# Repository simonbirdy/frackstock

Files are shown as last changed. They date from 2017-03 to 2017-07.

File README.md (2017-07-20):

# frackstock
LED walking stick  for the Frackwoche 2017 www.frackwoche.ch

The LED walking stick contains 100 WS2812B RGB-LEDs which can be adressed seperately. The walking stick can be controlled with a accelometer or remotely via a 968 MHz RF-Link. This allows a master to control all walking sticks in range 

Videos showing the walking stick in Action:

(https://www.youtube.com/watch?v=WOQ_-gf9qqU)

(https://www.youtube.com/watch?v=yyVRBFyqIFY)

General Setup (Remote Control):

Android Device (WLAN) -> Sender (ESP2866 & RFM117) -> walking stick (RFM217 & STM32f0)

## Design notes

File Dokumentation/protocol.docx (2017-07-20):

# Sender Protocol

The Protocol consists out of 8 bytes:

START | SESSION | TARGET | COMMAND | PAR1 | PAR2 | PAR3 | CHECKSUM

# START

Hex-Value = 0xAA

1 | 0 | 1 | 0 | 1 | 0 | 1 | 0

Signals the start of a transmission.

# SESSION

B7 | B6 | B5 | B4 | B3 | B2 | B1 | B0

B7..B0 Number of session

The session number is used to differ between new commands and repeated commands. Each command is sent twice with the same session number to produce redundancy.

# TARGET

B7 | B6 | B5 | B4 | B3 | B2 | B1 | B0
MODE

B7..B6 00=MODE_ADRESS

01=MODE_EXCLUDE

10=MODE_MODULO

11=RESERVED

MODE_ADRESS:

B5..B0 Adress of device (Broadcast=0x3F) to receive Command

MODE_EXCLUDE:

B5..B0 Adress of device (Broadcast=0x3F) to ignore Command

MODE_MODULO

B2..B1 Modulo value (e.g 3-> every third device reacts on command)

B5..B3 Offset value (e.g. 1 -> device 1,4,7… 2-> device 2,5,8…)

## COMMAND

B7 | B6 | B5 | B4 | B3 | B2 | B1 | B0
Background

B7 0=Trigger Foreground Animation

1=Background Animation

B6..B0 Animation identifier

## PAR1..3

Parameters for the Animation

## CHECKSUM

B7 | B6 | B5 | B4 | B3 | B2 | B1 | B0

Checksum = SESSION+TARGET+COMMAND+PAR1+PAR2+PAR3

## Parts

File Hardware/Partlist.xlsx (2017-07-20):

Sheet: Tabelle1
Part | Value | Device | Package | Library | Supplier | Order number | Price
U2 |  | MCP1700-T-3302 |  |  | Farnell | 1296592 | 0.343 | 50
U4 |  | TPS61235 |  |  | Mouser | 595-TPS61235PRWLR | 1.8 | 5
U3 |  | STM32F031 |  |  | Farnell | 2503233 | 1.41 | 50
U1 |  | MMA7660FCR1 |  |  | Farnell | 2080493 | 1.24 | 40
U5 |  | RFM217 |  |  | vogelsi1 |  |  | 39
C7,C8,C9,C14 | 22uF / 10V | Kondensator | 805 |  | Mouser | 81-GRM188R61A226ME5D (http://www.mouser.ch/ProductDetail/Murata-Electronics/GRM188R61A226ME15D/) |  | 200
C13 | 10 uF / 10V | Kondensator | 805 |  | Mouser |  |  | 50
L1 | 1 uH | SRN80401A |  |  | Mouser | 652-SRN8040-1R0Y | 0.4 | 5
C1,C3,C5 | 100nF |  | 603 |  | Mouser | 81-GRM39X104K25 |  | 150
R1 | 1k |  | 603 |  | Mouser | 667-ERJ-1GEJ102C |  | 100
R2,R3 | 4.7k |  | 603 |  | Mouser | 667-ERJ-1GEJ472C |  | 100
R9,R10 | 10k |  | 603 |  | Mouser | 603-RC0201FR-0710KL |  | 100
R11 | 22k |  | 603 |  | Mouser | 603-RC0201FR-0722KL | 0.01 | 100
K1 |  |  |  |  | Farnell | 1565585 |  | -
 |  | Batteriehalter |  |  |  |  | 1.3

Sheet: Tabelle2
Was | Wer | Wieviel | Bezahlt
LED Strip 4x | Ueli | 76
Livio Stöcke | Simon | 535
Livio Prototyp | Livio | 20
Led Strip 2x | Adrian | 38
Led Strip 6x | Simon | 104
PCB | Adrian | 142
LaserCutting | Simon | 220
Bauteile | Ueli | 231
Holz | Sven | 54
Bauteile | Simon | 116.75
Schrauben & Co | Ueli | 85.2
Gehstockpuffer | Simon | 20
 |  | 1641.95 | 49.75606061
Kosten pro Stock
LED |  | 6.61
PCB |  | 14.84
Stock |  | 16.82
Knauf |  | 10.88
Total |  | 49.15

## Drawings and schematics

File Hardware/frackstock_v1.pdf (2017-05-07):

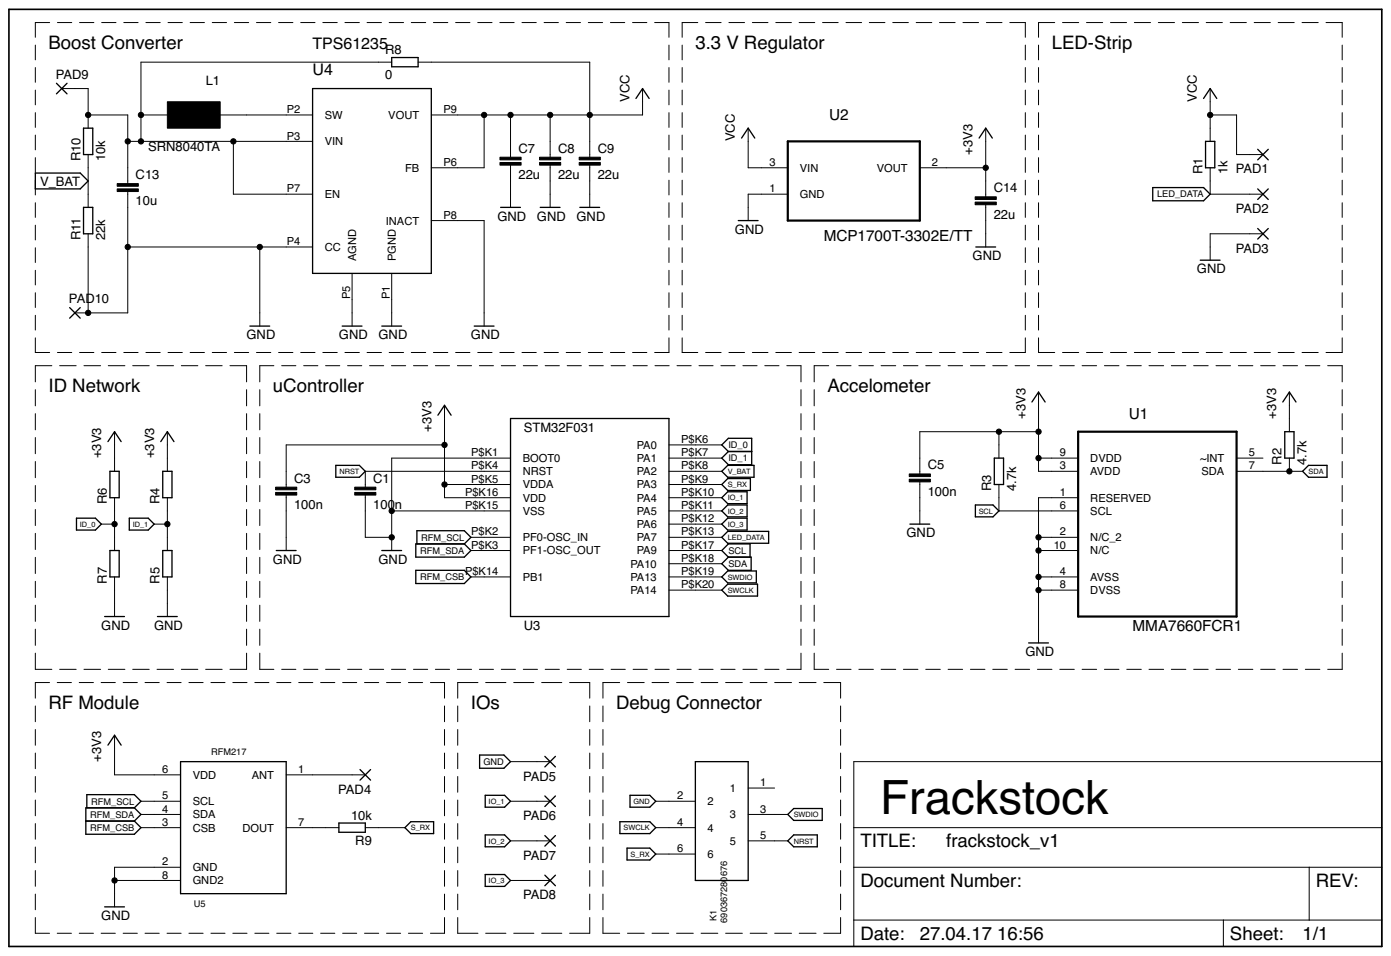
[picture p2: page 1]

Document Number: | REV:

Date: 27.04.17 16:56 | Sheet: 1/1

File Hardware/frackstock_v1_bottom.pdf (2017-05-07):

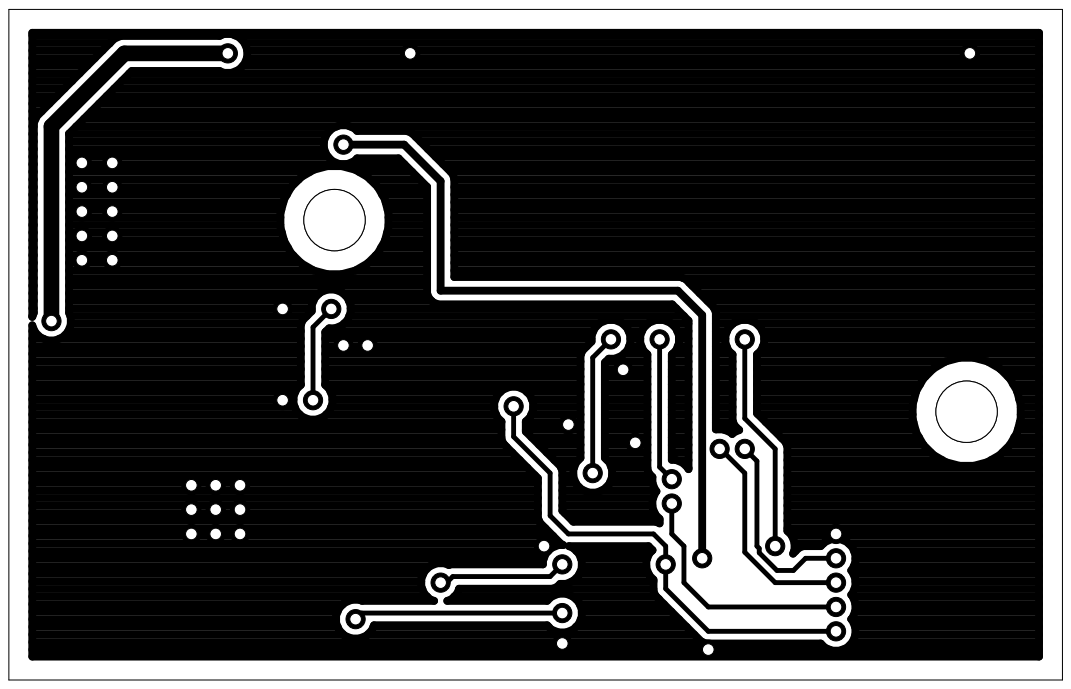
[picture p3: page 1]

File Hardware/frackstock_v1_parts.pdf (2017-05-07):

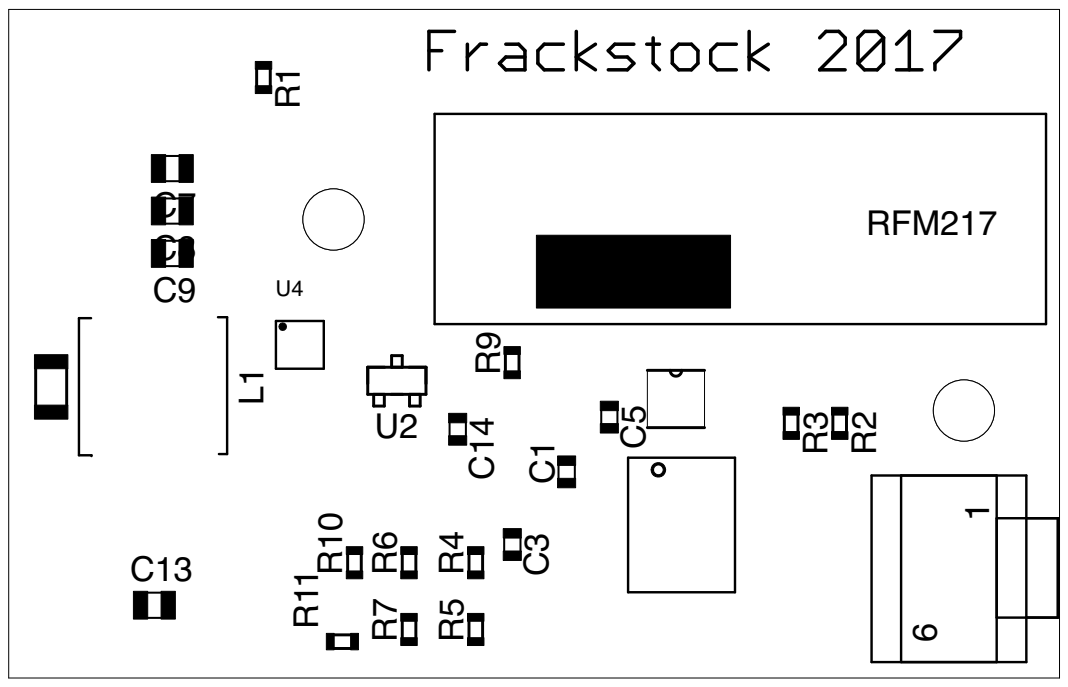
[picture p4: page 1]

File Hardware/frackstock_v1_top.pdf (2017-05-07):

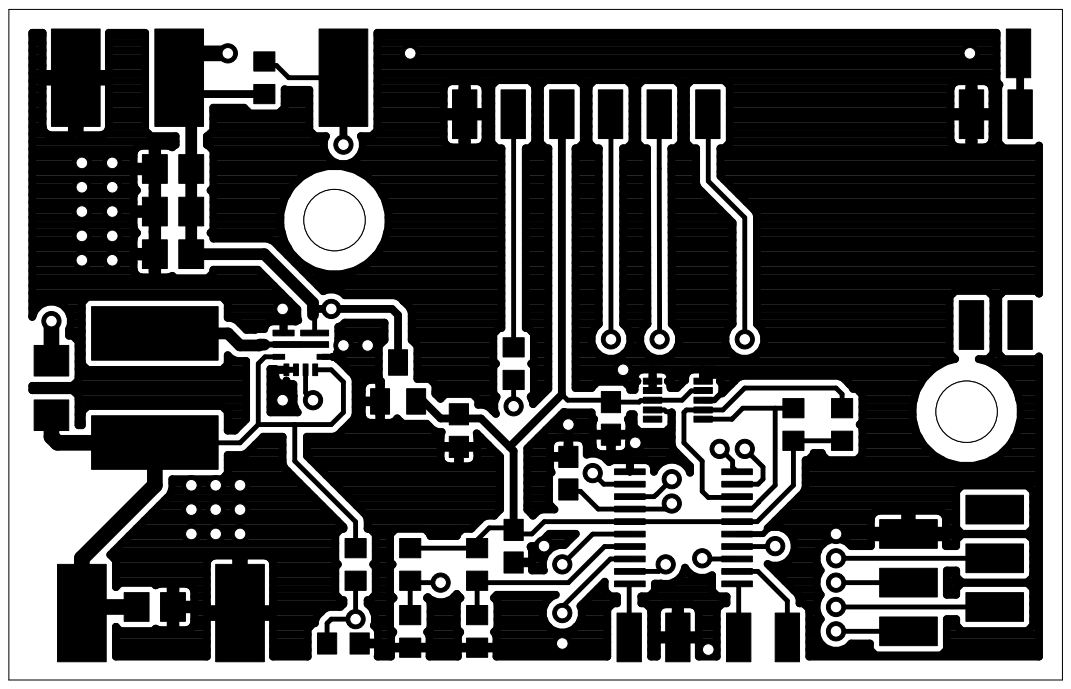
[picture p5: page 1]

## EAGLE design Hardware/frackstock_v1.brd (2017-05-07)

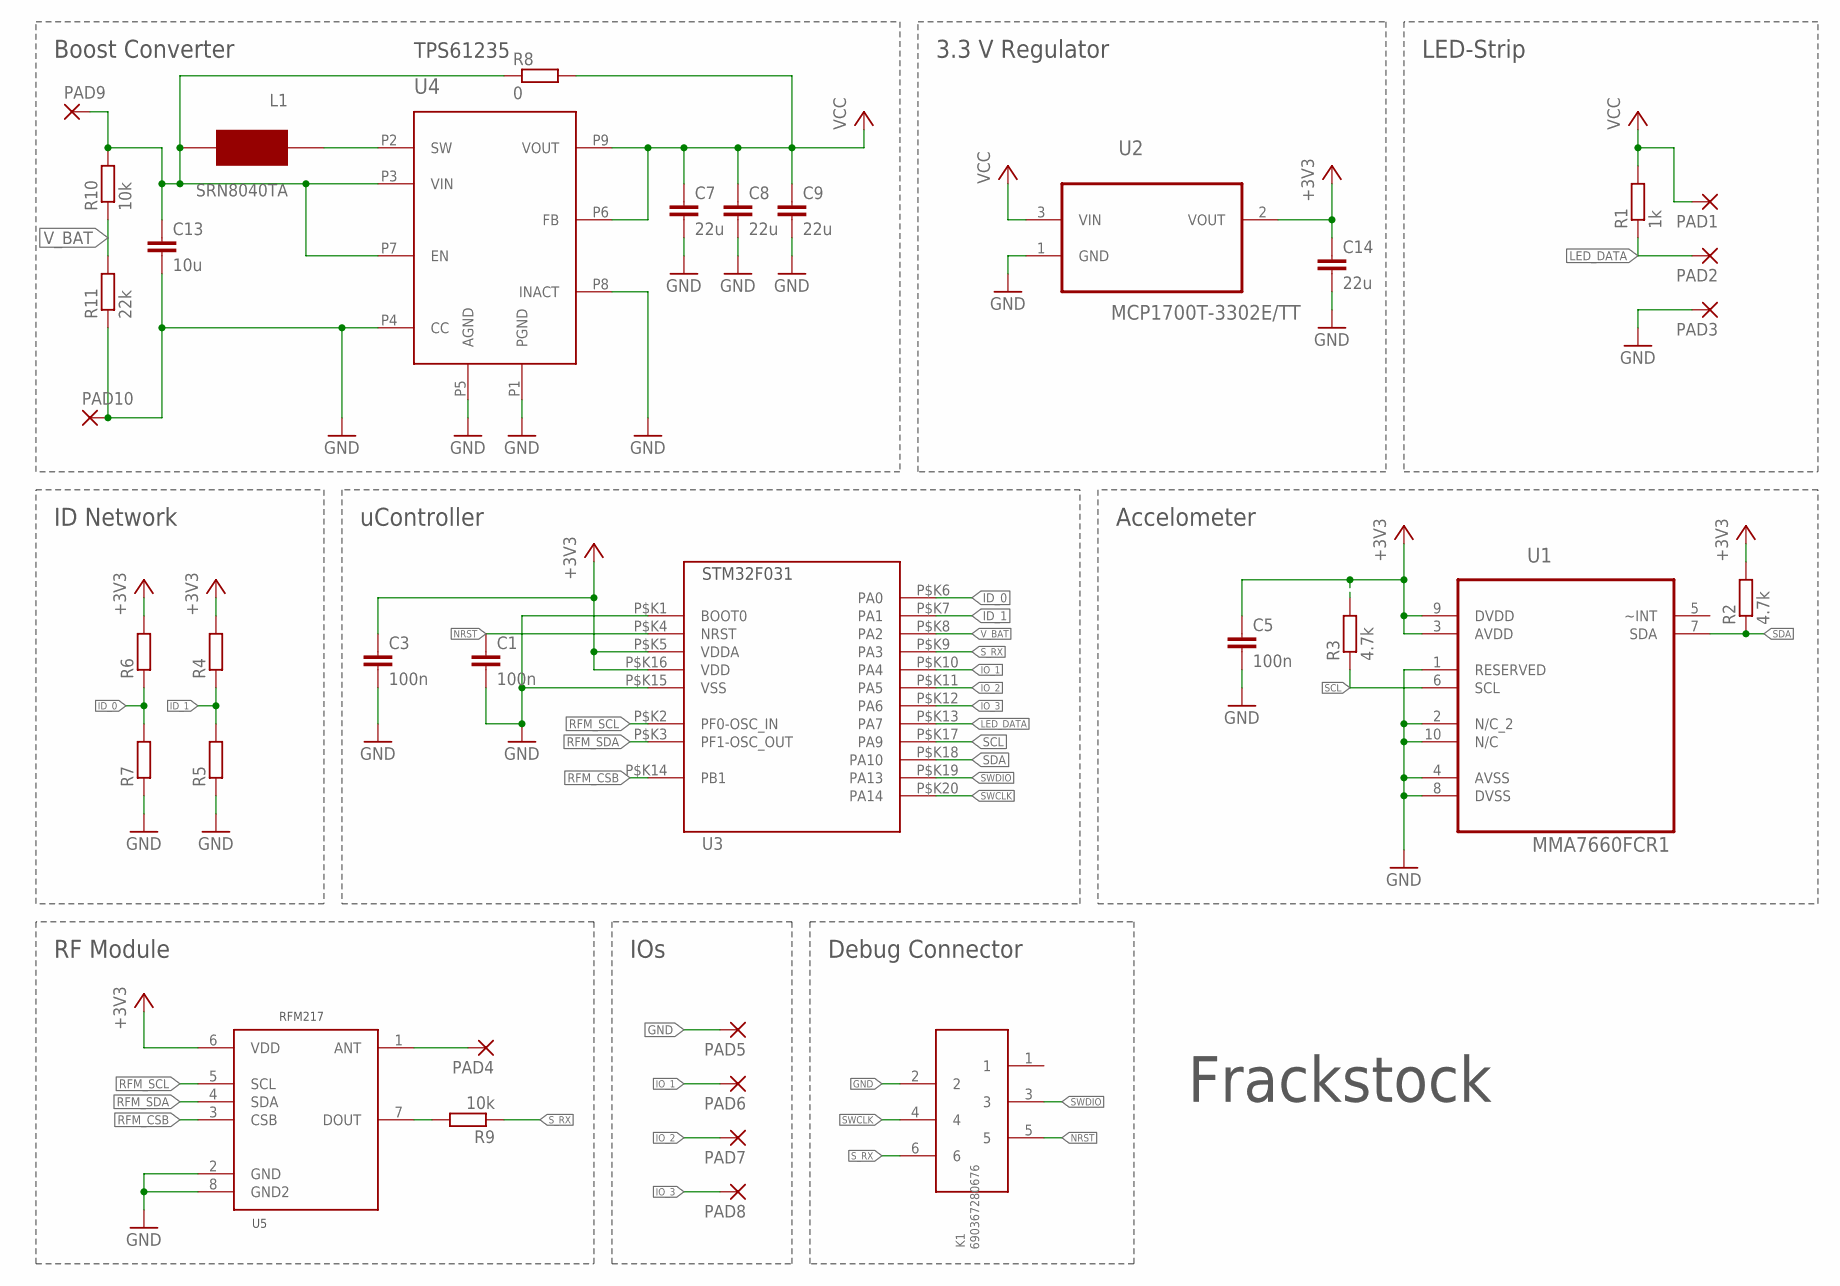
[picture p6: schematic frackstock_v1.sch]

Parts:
C1, C3, C5: 100n; C0603
C7, C8, C9: 22u; C0805
C13: 10u; C0805
C14: 22u; C0603
K1: 690367280676
L1: SRN8040TA; SRN8040TA_PACK
PAD1, PAD2, PAD3, PAD9, PAD10: SMD5; SMD2,54-5,08
PAD4, PAD5, PAD6, PAD7, PAD8: SMD2; SMD1,27-2,54
R1: 1k; R0603
R2, R3: 4.7k; R0603
R4, R5, R6, R7: R-EU_R0603; R0603
R8: 0; R1206
R9, R10: 10k; R0603
R11: 22k; R0603
U1: MMA7660FCR1; DFN300X300X100-10N
U2: MCP1700T-3302E/TT; SOT95P237X112-3N
U3: STM32F031; TSSOP20
U4: TPS61235; VQFN
U5: RFM217; RFM217_PACK

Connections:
+3V3: C3.1, C5.1, C14.1, R2.2, R3.2, R4.2, R6.2, U1.3 (AVDD), U1.9 (DVDD), U2.2 (VOUT), U3.P$K5 (VDDA), U3.P$K16 (VDD), U5.6 (VDD)
GND: C1.2, C3.2, C5.2, C7.2, C8.2, C9.2, C13.2, C14.2, K1.2, PAD3.1, PAD5.1, PAD10.1, R5.1, R7.1, R11.1, U1.1 (RESERVED), U1.2 (N/C_2), U1.4 (AVSS), U1.8 (DVSS), U1.10 (N/C), U2.1 (GND), U3.P$K1 (BOOT0), U3.P$K15 (VSS), U4.P1 (PGND), U4.P4 (CC), U4.P5 (AGND), U4.P8 (INACT), U5.2 (GND), U5.8 (GND2)
ID_0: R6.1, R7.2, U3.P$K6 (PA0)
ID_1: R4.1, R5.2, U3.P$K7 (PA1)
IO_1: PAD6.1, U3.P$K10 (PA4)
IO_2: PAD7.1, U3.P$K11 (PA5)
IO_3: PAD8.1, U3.P$K12 (PA6)
LED_DATA: PAD2.1, R1.1, U3.P$K13 (PA7)
unnamed: R9.2, U5.7 (DOUT)
unnamed: PAD4.1, U5.1 (ANT)
unnamed: L1.2, U4.P2 (SW)
unnamed: C13.1, L1.1, PAD9.1, R8.1, R10.2, U4.P3 (VIN), U4.P7 (EN)
NRST: C1.1, K1.5, U3.P$K4 (NRST)
RFM_CSB: U3.P$K14 (PB1), U5.3 (CSB)
RFM_SCL: U3.P$K2 (PF0-OSC_IN), U5.5 (SCL)
RFM_SDA: U3.P$K3 (PF1-OSC_OUT), U5.4 (SDA)
SCL: R3.1, U1.6 (SCL), U3.P$K17 (PA9)
SDA: R2.1, U1.7 (SDA), U3.P$K18 (PA10)
SWCLK: K1.4, U3.P$K20 (PA14)
SWDIO: K1.3, U3.P$K19 (PA13)
S_RX: K1.6, R9.1, U3.P$K9 (PA3)
VCC: C7.1, C8.1, C9.1, PAD1.1, R1.2, R8.2, U2.3 (VIN), U4.P6 (FB), U4.P9 (VOUT)
V_BAT: R10.1, R11.2, U3.P$K8 (PA2)

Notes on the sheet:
Frackstock
Boost Converter
3.3 V Regulator
LED-Strip
ID Network
uController
Debug Connector
IOs
RF Module
Accelometer

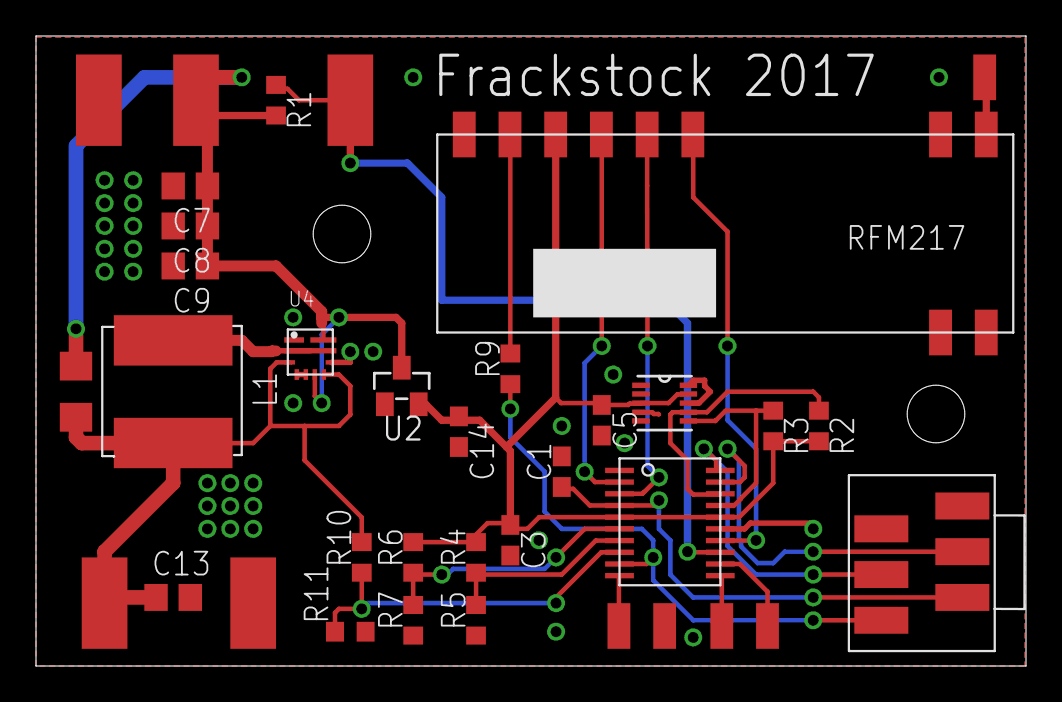
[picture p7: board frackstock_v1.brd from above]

Board: 2 copper layers, 55.0 x 35.0 mm, 36 parts (0 on the bottom side), 23 nets.

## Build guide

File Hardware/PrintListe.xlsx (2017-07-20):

Print | R4 | R5 | R6 | R7 | Bemerkungen | Name |  | 0
1 |  | 0 | 0 |  |  |  | 300 | 33 | 405.9099099
2 | 200 | 33 | 0 |  |  |  | 30 | 12 | 1170.285714
3 | 30 | 12 | 0 |  |  |  | 16 | 12 | 1755.428571
4 | 16 | 12 | 0 |  |  |  | 7.5 | 10 | 2340.571429
5 | 7.5 | 10 | 0 |  |  |  | 12 | 30 | 2925.714286
6 | 12 | 30 | 0 |  |  |  | 2 | 12 | 3510.857143
7 | 2 | 12 | 0 |  |  |  | 0 |  | #DIV/0!
8 | 0 |  | 0
9 |  | 0 | 200 | 33
10 | 200 | 33 | 200 | 33
11 | 30 | 12 | 200 | 33
12 | 16 | 12 | 200 | 33
13 | 7.5 | 10 | 200 | 33
14 | 12 | 30 | 200 | 33
15 | 2 | 12 | 200 | 33
16 | 0 |  | 200 | 33
17 |  | 0 | 30 | 12
18 | 200 | 33 | 30 | 12
19 | 30 | 12 | 30 | 12
20 | 16 | 12 | 30 | 12
21 | 7.5 | 10 | 30 | 12
22 | 12 | 30 | 30 | 12
23 | 2 | 12 | 30 | 12
24 | 0 |  | 30 | 12
25 |  | 0 | 16 | 12
26 | 200 | 33 | 16 | 12
27 | 30 | 12 | 16 | 12
28 | 16 | 12 | 16 | 12
29 | 7.5 | 10 | 16 | 12
30 | 12 | 30 | 16 | 12
31 | 2 | 12 | 16 | 12
32 | 0 |  | 16 | 12
33 |  | 0 | 7.5 | 10
34 | 200 | 33 | 7.5 | 10
35 | 30 | 12 | 7.5 | 10
36 | 16 | 12 | 7.5 | 10
37 | 7.5 | 10 | 7.5 | 10
38 | 12 | 30 | 7.5 | 10
39 | 2 | 12 | 7.5 | 10
40 | 0 |  | 7.5 | 10

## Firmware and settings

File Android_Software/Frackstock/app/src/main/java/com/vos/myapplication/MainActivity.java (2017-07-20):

package com.vos.myapplication;

import android.content.Intent;
import android.graphics.Color;
import android.os.Bundle;
import android.support.design.widget.FloatingActionButton;
import android.support.v7.app.AppCompatActivity;
import android.support.v7.widget.Toolbar;
import android.util.Log;
import android.view.MotionEvent;
import android.view.View;
import android.view.Menu;
import android.view.MenuItem;
import android.view.WindowManager;
import android.widget.Button;
import android.widget.EditText;
import android.widget.SeekBar;


public class MainActivity extends AppCompatActivity {

    Button bTriggers, bStripe, bSparks, bConstColor, bRainbow,bBlink,bRain,bStrobo;
    MainActivity thisActivity;
    SeekBar sbGlobalBrightness;

    static int R_SPARKS = 1;
    static int R_STRIPE = 2;
    static int R_CONST = 3;
    static int R_RAINBOW = 4;
    static int R_BLINK = 5;
    static int R_RAIN = 6;
    static int R_STROBO = 7;

    int Sparkscolor1;
    int SparkModulo;
    int SparkSpeed;


    int StripeColor1,StripeColor2;
    int StripeBrightness,StripeLength,StripeSpeed;

    int ConstColor1,ConstColor2,ConstBrightness;

    int RainbowSpeed;

    int BlinkColor1,BlinkColor2,BlinkColor3,BlinkColor4;

    int RainColor1,RainColor2,RainColor3,RainColor4;
    int RainSpeed,RainLength;

    int StroboColor1;
    int StroboLength,StroboPause;


    @Override
    protected void onCreate(Bundle savedInstanceState) {
        super.onCreate(savedInstanceState);
        setContentView(R.layout.activity_main);
        Toolbar toolbar = (Toolbar) findViewById(R.id.toolbar);
        setSupportActionBar(toolbar);


        bBlink = (Button) findViewById(R.id.bBlink);
        bStripe = (Button)  findViewById(R.id.bStripeLaunch);
        bSparks = (Button) findViewById(R.id.bSparksLaunch);
        bConstColor = (Button)    findViewById(R.id.bConstColor);
        bRainbow = (Button)    findViewById(R.id.bRainbow);
        bRain = (Button) findViewById(R.id.bRain);
        bStrobo = (Button) findViewById(R.id.bStrobo);
        bTriggers = (Button) findViewById(R.id.bTrigger);
        sbGlobalBrightness = (SeekBar) findViewById(R.id.sbGlobalBrightness);


        sbGlobalBrightness.setProgress(128);

        thisActivity = this;


        /* Stripe */
        StripeColor1 = Color.RED;
        StripeColor2 = Color.GREEN;
        StripeBrightness = 8;
        StripeLength = 15;
        StripeSpeed = 1;

        bStripe.setOnClickListener(new View.OnClickListener() {
           @Override
           public void onClick(View v) {
               Intent intent = new Intent(thisActivity, stripeActivity.class);
               intent.putExtra("Color1",StripeColor1);
               intent.putExtra("Color2",StripeColor2);
               intent.putExtra("Brightness",StripeBrightness);
               intent.putExtra("Length",StripeLength);
               intent.putExtra("Speed",StripeSpeed);
               intent.putExtra("GlobalBrightness",sbGlobalBrightness.getProgress());
               startActivityForResult(intent,R_STRIPE);
           }
       });


        /*   Sparks    */
        Sparkscolor1 = Color.RED;
        SparkModulo = 5;
        SparkSpeed = 1;
        bSparks.setOnClickListener(new View.OnClickListener() {
            @Override
            public void onClick(View v) {
                Intent intent = new Intent(thisActivity, sparkActivity.class);
                intent.putExtra("Color1", Sparkscolor1);
                intent.putExtra("Modulo",SparkModulo);
                intent.putExtra("Speed",SparkSpeed);
                intent.putExtra("GlobalBrightness",sbGlobalBrightness.getProgress());

                startActivityForResult(intent,R_SPARKS);

            }
        });

        /* Const Color */
        ConstColor1 = Color.RED;
        ConstColor2 = Color.GREEN;
        ConstBrightness = 10;
        bConstColor.setOnClickListener(new View.OnClickListener() {
            @Override
            public void onClick(View v) {
                Intent intent = new Intent(thisActivity, ConstColorActivity.class);
                intent.putExtra("Color1",ConstColor1);
                intent.putExtra("Color2",ConstColor2);
                intent.putExtra("Brightness",ConstBrightness);
                intent.putExtra("GlobalBrightness",sbGlobalBrightness.getProgress());

                startActivityForResult(intent,R_CONST);
            }
        });


        /* Rainbow */

        RainbowSpeed = 20;

        bRainbow.setOnClickListener(new View.OnClickListener() {
            @Override
            public void onClick(View v) {
                Intent intent = new Intent(thisActivity, RainbowActivity.class);
                intent.putExtra("Speed",RainbowSpeed);
                intent.putExtra("GlobalBrightness",sbGlobalBrightness.getProgress());

                startActivityForResult(intent,R_RAINBOW);
            }
        });


        /* Blink */
        BlinkColor1 = Color.RED;
        BlinkColor2 = Color.GREEN;
        BlinkColor3 = Color.BLUE;
        BlinkColor4 = Color.WHITE;

        bBlink.setOnClickListener(new View.OnClickListener() {
            @Override
            public void onClick(View v) {
                Intent intent = new Intent(thisActivity, BlinkActivity.class);
                intent.putExtra("Color1",BlinkColor1);
                intent.putExtra("Color2",BlinkColor2);
                intent.putExtra("Color3",BlinkColor3);
                intent.putExtra("Color4",BlinkColor4);
                intent.putExtra("GlobalBrightness",sbGlobalBrightness.getProgress());

                startActivityForResult(intent,R_BLINK);
            }
        });


        /* Rain */
        RainColor1 = Color.RED;
        RainColor2 = Color.GREEN;
        RainColor3 = Color.BLUE;
        RainColor4 = Color.WHITE;

        RainSpeed = 2;
        RainLength = 7;

        bRain.setOnClickListener(new View.OnClickListener() {
            @Override
            public void onClick(View v) {
                Intent intent = new Intent(thisActivity, RainActivity.class);
                intent.putExtra("Color1",RainColor1);
                intent.putExtra("Color2",RainColor2);
                intent.putExtra("Color3",RainColor3);
                intent.putExtra("Color4",RainColor4);
                intent.putExtra("Speed",RainSpeed);
                intent.putExtra("Length",RainLength);
                intent.putExtra("GlobalBrightness",sbGlobalBrightness.getProgress());

                startActivityForResult(intent,R_RAIN);
            }
        });

        StroboColor1 = Color.RED;
        StroboLength = 1;
        StroboPause = 2;

        bStrobo.setOnClickListener(new View.OnClickListener() {
            @Override
            public void onClick(View v) {
                Intent intent = new Intent(thisActivity, stroboActivity.class);
                intent.putExtra("Color1",StroboColor1);
                intent.putExtra("Length",StroboLength);
                intent.putExtra("Pause",StroboPause);
                intent.putExtra("GlobalBrightness",sbGlobalBrightness.getProgress());

                startActivityForResult(intent,R_STROBO);
            }
        });


        /* Triggers */

        bTriggers.setOnClickListener(new View.OnClickListener() {
            @Override
            public void onClick(View v) {
                Intent intent = new Intent(thisActivity, TriggerActivity.class);
                intent.putExtra("StripeColor1"      ,StripeColor1);
                intent.putExtra("StripeColor2"      ,StripeColor2);
                intent.putExtra("StripeBrightness"  ,StripeBrightness);
                intent.putExtra("StripeLength"      ,StripeLength);
                intent.putExtra("StripeSpeed"       ,StripeSpeed);
                intent.putExtra("ConstColor1"       ,ConstColor1);
                intent.putExtra("ConstColor2"       ,ConstColor2);
                intent.putExtra("ConstBrightness"       ,ConstBrightness);

                intent.putExtra("RainbowSpeed"      ,RainbowSpeed);
                intent.putExtra("BlinkColor1"       ,BlinkColor1);
                intent.putExtra("BlinkColor2"       ,BlinkColor2);
                intent.putExtra("BlinkColor3"       ,BlinkColor3);
                intent.putExtra("BlinkColor4"       ,BlinkColor4);
                intent.putExtra("RainColor1"        ,RainColor1);
                intent.putExtra("RainColor2"        ,RainColor2);
                intent.putExtra("RainColor3"        ,RainColor3);
                intent.putExtra("RainColor4"        ,RainColor4);

                intent.putExtra("RainSpeed"         ,RainSpeed);
                intent.putExtra("RainLength"        ,RainLength);

                intent.putExtra("StroboColor1"      ,StroboColor1);
                intent.putExtra("StroboLength"      ,StroboLength);
                intent.putExtra("StroboPause"       ,StroboPause);

                intent.putExtra("SparkColor1"      ,Sparkscolor1);
                intent.putExtra("SparkModulo"      ,SparkModulo);
                intent.putExtra("SparkSpeed"       ,SparkSpeed);
                intent.putExtra("GlobalBrightness",sbGlobalBrightness.getProgress());


                startActivityForResult(intent,0);
            }
        });
    }




    @Override
    public boolean onCreateOptionsMenu(Menu menu) {
        // Inflate the menu; this adds items to the action bar if it is present.
        getMenuInflater().inflate(R.menu.menu_main, menu);
        return true;
    }

    @Override
    protected void onActivityResult(int requestCode, int resultCode, Intent data) {
        // Check which request we're responding to
        if (requestCode == R_SPARKS) {
            // Make sure the request was successful
            if (resultCode == RESULT_OK) {
                // The user picked a contact.
                // The Intent's data Uri identifies which contact was selected.
                Sparkscolor1 = data.getIntExtra("Color1",Color.RED);
                SparkModulo = data.getIntExtra("Modulo",5);
                SparkSpeed = data.getIntExtra("Speed",1);
                // Do something with the contact here (bigger example below)
            }
        }

        if(requestCode == R_STRIPE) {
            // Make sure the request was successful
            if (resultCode == RESULT_OK) {
                // The user picked a contact.
                // The Intent's data Uri identifies which contact was selected.
                StripeColor1 = data.getIntExtra("Color1",Color.RED);
                StripeColor2 = data.getIntExtra("Color2",Color.GREEN);
                StripeBrightness = data.getIntExtra("Brightness",7);
                StripeLength = data.getIntExtra("Length",15);
                StripeSpeed = data.getIntExtra("Speed",1);
                // Do something with the contact here (bigger example below)
            }
        }

        if(requestCode == R_CONST) {
            // Make sure the request was successful
            if (resultCode == RESULT_OK) {
                // The user picked a contact.
                // The Intent's data Uri identifies which contact was selected.
                ConstColor1 = data.getIntExtra("Color1",Color.RED);
                ConstColor2 = data.getIntExtra("Color2",Color.GREEN);
                ConstBrightness = data.getIntExtra("Brightness",10);
                // Do something with the contact here (bigger example below)
            }
        }

        if(requestCode == R_RAINBOW) {
            // Make sure the request was successful
            if (resultCode == RESULT_OK) {
                // The user picked a contact.
                // The Intent's data Uri identifies which contact was selected.
                RainbowSpeed = data.getIntExtra("Speed",20);

                // Do something with the contact here (bigger example below)
            }
        }

        if(requestCode == R_BLINK) {
            // Make sure the request was successful
            if (resultCode == RESULT_OK) {
                // The user picked a contact.
                // The Intent's data Uri identifies which contact was selected.
                BlinkColor1 = data.getIntExtra("Color1",Color.RED);
                BlinkColor2 = data.getIntExtra("Color2",Color.GREEN);
                BlinkColor3 = data.getIntExtra("Color3",Color.BLUE);
                BlinkColor4 = data.getIntExtra("Color4",Color.WHITE);

                // Do something with the contact here (bigger example below)
            }
        }

        if(requestCode == R_RAIN) {
            // Make sure the request was successful
            if (resultCode == RESULT_OK) {
                // The user picked a contact.
                // The Intent's data Uri identifies which contact was selected.
                RainColor1 = data.getIntExtra("Color1",Color.RED);
                RainColor2 = data.getIntExtra("Color2",Color.GREEN);
                RainColor3 = data.getIntExtra("Color3",Color.BLUE);
                RainColor4 = data.getIntExtra("Color4",Color.WHITE);
                RainSpeed = data.getIntExtra("Speed",7);
                RainLength = data.getIntExtra("Length",7);

                // Do something with the contact here (bigger example below)
            }
        }

        if(requestCode == R_STROBO) {
            // Make sure the request was successful
            if (resultCode == RESULT_OK) {
                // The user picked a contact.
                // The Intent's data Uri identifies which contact was selected.
                StroboColor1 = data.getIntExtra("Color1",Color.RED);
                StroboLength = data.getIntExtra("Length",1);
                StroboPause = data.getIntExtra("Pause",2);


                // Do something with the contact here (bigger example below)
            }
        }
    }

    @Override
    public boolean onOptionsItemSelected(MenuItem item) {
        // Handle action bar item clicks here. The action bar will
        // automatically handle clicks on the Home/Up button, so long
        // as you specify a parent activity in AndroidManifest.xml.
        int id = item.getItemId();

        //noinspection SimplifiableIfStatement
        if (id == R.id.action_settings) {
            return true;
        }

        return super.onOptionsItemSelected(item);
    }


}

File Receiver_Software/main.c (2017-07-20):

/*----------------------------------------------------------------------------
 * Name:    Blinky.c
 * Purpose: LED Flasher
 *----------------------------------------------------------------------------
 * This file is part of the uVision/ARM development tools.
 * This software may only be used under the terms of a valid, current,
 * end user licence from KEIL for a compatible version of KEIL software
 * development tools. Nothing else gives you the right to use this software.
 *
 * This software is supplied "AS IS" without warranties of any kind.
 *
 * Copyright (c) 2015 Keil - An ARM Company. All rights reserved.
 *----------------------------------------------------------------------------*/


#include "stm32f0xx.h"                  // Device header
#include "led.h"
#include "sc.h"
#include "usart.h"
#include "rfm.h"
#include "animation.h"
#include "info.h"
#include "accel.h"
#include "adc.h"
#include "control.h"

/*----------------------------------------------------------------------------
 * SystemCoreClockConfigure: configure SystemCoreClock using HSI
                             (HSE is not populated on Discovery board)
 *----------------------------------------------------------------------------*/
void SystemCoreClockConfigure(void) {

	
  RCC->CR |= ((uint32_t)RCC_CR_HSION);                     // Enable HSI
  while ((RCC->CR & RCC_CR_HSIRDY) == 0);                  // Wait for HSI Ready

  RCC->CFGR = RCC_CFGR_SW_HSI;                             // HSI is system clock
  while ((RCC->CFGR & RCC_CFGR_SWS) != RCC_CFGR_SWS_HSI);  // Wait for HSI used as system clock

  FLASH->ACR  = FLASH_ACR_PRFTBE;                          // Enable Prefetch Buffer
  FLASH->ACR |= FLASH_ACR_LATENCY;                         // Flash 1 wait state

  RCC->CFGR |= RCC_CFGR_HPRE_DIV1;                         // HCLK = SYSCLK
  RCC->CFGR |= RCC_CFGR_PPRE_DIV1;                         // PCLK = HCLK

  RCC->CR &= ~RCC_CR_PLLON;                                // Disable PLL

  //  PLL configuration:  = HSI/2 * 12 = 48 MHz
  RCC->CFGR &= ~(RCC_CFGR_PLLSRC | RCC_CFGR_PLLXTPRE | RCC_CFGR_PLLMULL);
  RCC->CFGR |=  (RCC_CFGR_PLLSRC_HSI_Div2 | RCC_CFGR_PLLMULL12);

  RCC->CR |= RCC_CR_PLLON;                                 // Enable PLL
  while((RCC->CR & RCC_CR_PLLRDY) == 0) __NOP();           // Wait till PLL is ready

  RCC->CFGR &= ~RCC_CFGR_SW;                               // Select PLL as system clock source
  RCC->CFGR |=  RCC_CFGR_SW_PLL;
  while ((RCC->CFGR & RCC_CFGR_SWS) != RCC_CFGR_SWS_PLL);  // Wait till PLL is system clock src
	
	RCC->CR &= ~RCC_CR_HSEON;
}


uint8_t device_adress = DEV_ADRESS;

/*----------------------------------------------------------------------------
 * main: initialize and start the system
 *----------------------------------------------------------------------------*/
int main (void) {
	uint32_t i = 0;
	
			//Colors
		
		// initialize peripherals
		SystemCoreClockConfigure();               // configure System Clock
		SystemCoreClockUpdate();
		RCC->AHBENR |= RCC_AHBENR_GPIOBEN | RCC_AHBENR_GPIOAEN;

		//Init Functions
		led_initialize();
		sc_initialize();
		usart_initialize();
		rfm_initialize();
		accel_init();
		adc_initialize();
		animation_initialize();
		control_init();
	
		device_adress = adc_getID();

		while(1){
			//GPIOA->BSRR = GPIO_BSRR_BS_12;
			adc_cycle();
			accel_cycle();
			control_cycle();
			animation_cycle();
			led_cycle();
			usart_cycle();
			//GPIOA->BSRR = GPIO_BSRR_BR_12;

		
			
			while(sc_waitForCycle()==0 && usart_waiting()){
				usart_checkNewCommand();
			}				

	}
}

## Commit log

2017-05-07 Hardware Added
    Added Schematic and knob design
    Software Receiver: Added Accel module
    [Partlist.xlsx, PrintListe.xlsx, frackstock_v1.brd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]
2017-07-20 Update Frackwoche Version
    Android Software
    Receiver Software
    [Partlist.xlsx, PrintListe.xlsx]

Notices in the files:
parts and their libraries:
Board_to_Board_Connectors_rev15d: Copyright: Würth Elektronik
